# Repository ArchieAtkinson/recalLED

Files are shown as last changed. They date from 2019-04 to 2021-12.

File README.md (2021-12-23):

# recalLED

recalLED is a hand held PCB Simon Says Game. The PCB has four different coloured LEDs and four buttons. Each round a sequence of lights will flash. Once the sequence is over you must use the buttons to input sequence back. If you get it right the green LED flashes and you go to the next level which increase the number of flashes in a sequences. If you lose the red LED will flash and you will go back to the beginning. The game remembers your score and flashes the number of levels you have won when you turn it on. For more information, see the article I wrote about its creation on [my website](https://www.archieatkinson.com/recalled).

This repo contains the Eagle PCB and Schematic Files, Soildworks files for a case and the firmware. The firmware is written using the Arduino IDE and can be uploaded to the MCU using an Arduino as a programmer. It runs off a single CR2032 battery.

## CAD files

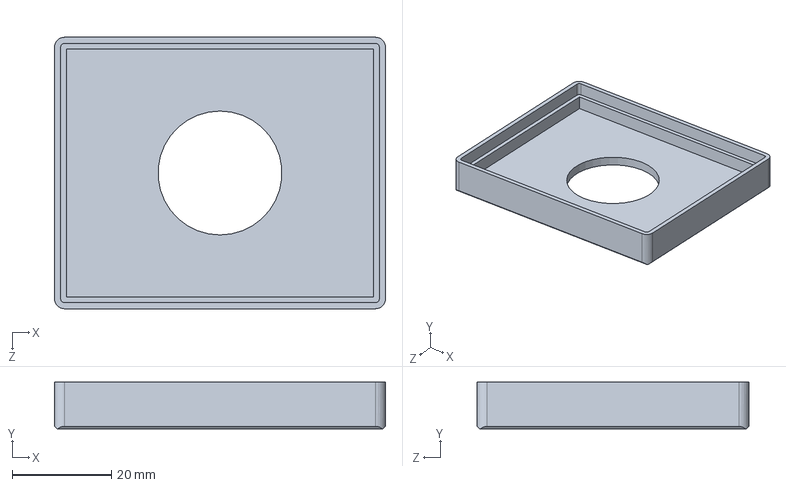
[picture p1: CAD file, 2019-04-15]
SoildWorks Files/Bottom.SLDPRT
66.8 x 9.40 x 54.8 mm

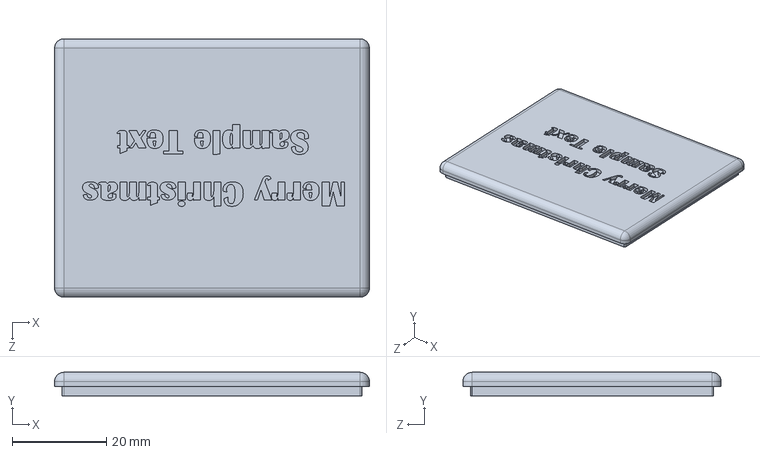
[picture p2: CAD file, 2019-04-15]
SoildWorks Files/Top.SLDPRT
66.8 x 5.00 x 54.8 mm

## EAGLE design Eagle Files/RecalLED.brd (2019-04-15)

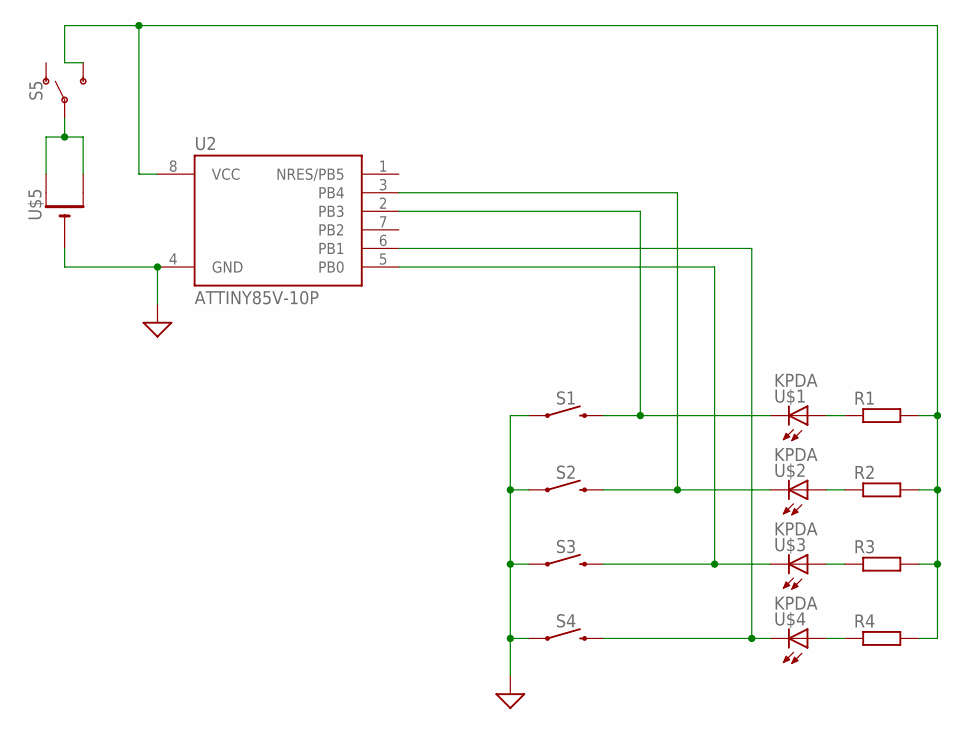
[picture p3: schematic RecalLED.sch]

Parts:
R1, R2, R3, R4: R-EU_M0805; M0805
S1, S2, S3, S4: MOMENTARY-SWITCH-SPST-SMD-6.2MM-TALL; TACTILE_SWITCH_SMD_6.2MM_TALL
S5: SWITCH-SPDT-SMD-RIGHT-ANGLE; SWITCH_SPST_SMD_A
U2: ATTINY85V-10P; PDIP08_300MIL
U$1, U$2, U$3, U$4: KPDA
U$5: CR2032SMT; CR2032-SMD

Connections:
GND: S1.A2 (1), S2.A2 (1), S3.A2 (1), S4.A2 (1), U2.4 (GND), U$5.-
unnamed: S1.B2 (2), U2.2 (PB3), U$1.P$2 (C)
unnamed: S2.B2 (2), U2.3 (PB4), U$2.P$2 (C)
unnamed: S3.B2 (2), U2.5 (PB0), U$3.P$2 (C)
unnamed: S4.B2 (2), U2.6 (PB1), U$4.P$2 (C)
unnamed: R4.1, U$4.P$1 (A)
unnamed: R3.1, U$3.P$1 (A)
unnamed: R2.1, U$2.P$1 (A)
unnamed: R1.1, U$1.P$1 (A)
unnamed: S5.2, U$5.+$1 (+), U$5.+$2 (+1)
unnamed: R1.2, R2.2, R3.2, R4.2, S5.3 (S), U2.8 (VCC)

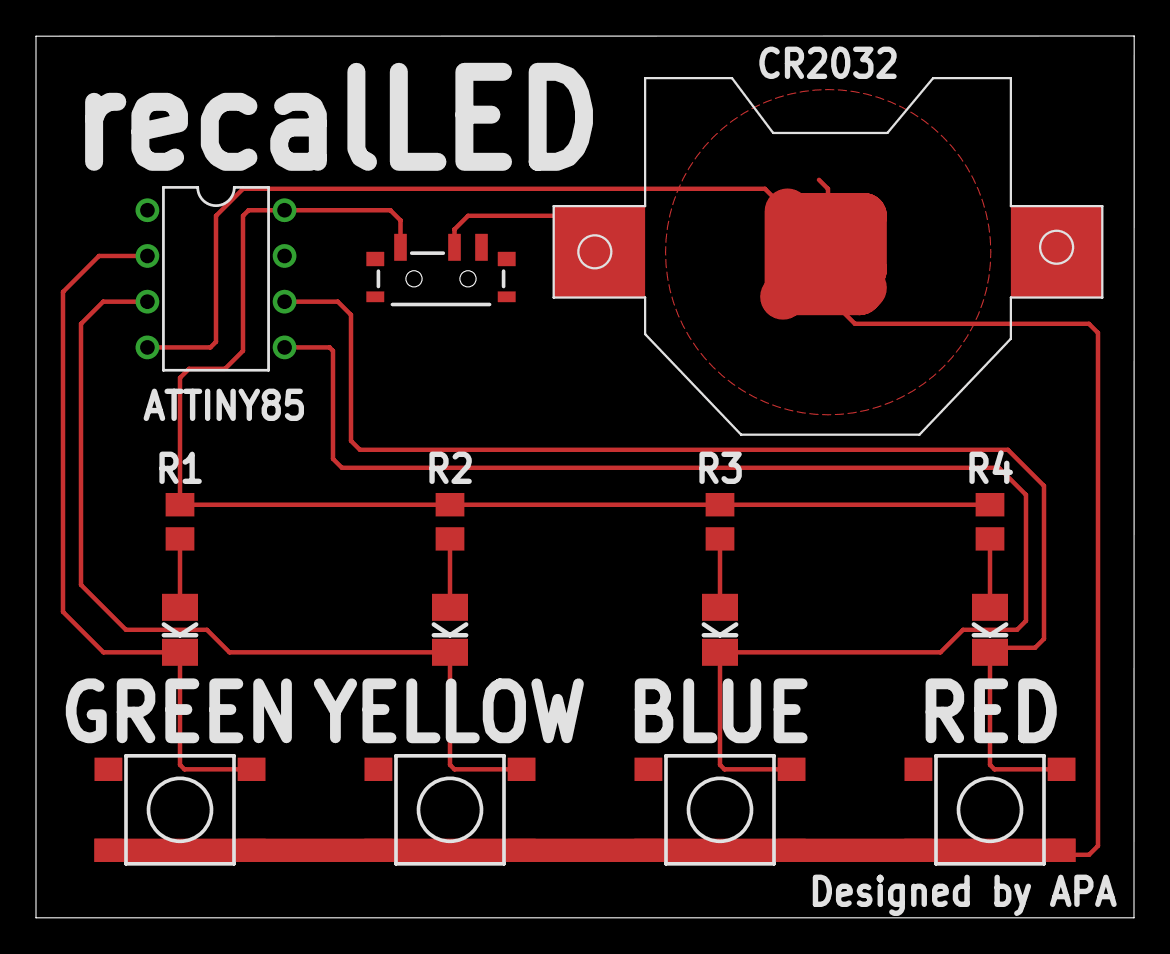
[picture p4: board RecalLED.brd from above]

Board: 2 copper layers, 61.0 x 49.0 mm, 15 parts (0 on the bottom side), 11 nets.

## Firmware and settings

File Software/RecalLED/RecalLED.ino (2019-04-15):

//By ProjectAPA
//Clock = 1MHz
//Has been flashed setting EEPROM byte 0 to 0
//Fuse High bits 3 has change to 1 to enable EEPROM

#include <EEPROM.h> //Allow EEPROM Libary
#define adc_disable() (ADCSRA &= ~(1<<ADEN)) //Disables ADC to save power

//Sets usable pins and number of pins
const int pins[] = {3, 4, 0, 1};
const int pinsLens = 3;

//Unused pin used to generate random number
const int RandPin = 2;

int ran;
int ans[128];
int in[128];

bool wait;

int buttonState[pinsLens + 1];
int lastButtonState[pinsLens + 1];
int reading[pinsLens + 1];
unsigned long lastDebounceTime[pinsLens + 1];

int i;
int j;
bool fail;

unsigned long debounceDelay = 15;
int level = 3;
byte highscore;

void setup()
{
  randomSeed(analogRead(RandPin)); //Gain random seed using unused pin

  //Turns all LED pins to Input with Pull-up
  MCUCR &= ~(1 << PUD);
  DDRB &= ~((1 << DDB0) | (1 << DDB1) | (1 << DDB3) | (1 << DDB4));
  PORTB |= ((1 << PORTB0) | (1 << PORTB1) | (1 << PORTB3) | (1 << PORTB4));
  
  delay(1000);
  
  adc_disable();

  //Starts up some cool flashing lights
  startup();

  delay(750);
  
  //reads high score to be displayed on start up
  highscore = EEPROM.read(0);
  for (i = 0; i < highscore; i++) {
    DDRB |= ((1 << DDB0) | (1 << DDB4));
    PORTB &= ~((1 << PORTB0) | (1 << PORTB4));
    delay(300);
    MCUCR &= ~(1 << PUD);
    DDRB &= ~((1 << DDB0) | (1 << DDB4));
    PORTB |= ((1 << PORTB0) | (1 << PORTB4));
    delay(300);
  }

}

void loop()
{
  delay(500);

  startround();

  delay(750);

  //Randomly flashes LED and store value
  for (i = 0; i <= level; i++) {
    ran = random(0, (pinsLens + 1));
    ans[i] = ran;
    digitalWrite(pins[ran], LOW);
    pinMode(pins[ran], OUTPUT);
    delay(250);
    pinMode(pins[ran], INPUT_PULLUP);
    delay(250);
  }
  
  MCUCR &= ~(1 << PUD);
  DDRB &= ~((1 << DDB0) | (1 << DDB1) | (1 << DDB3) | (1 << DDB4));
  PORTB |= ((1 << PORTB0) | (1 << PORTB1) | (1 << PORTB3) | (1 << PORTB4));


  //Sets debounce vars 
  for (int i = 0; i <= pinsLens; i++) {
    buttonState[i] = HIGH;
    lastButtonState[i] = HIGH;
    lastDebounceTime[i] = 0;
  }
  
  //Goes though each blink of LED and debounces inputs
  for (j = 0; j <= level; j++) {
    wait = true;
    while (wait == true) {
      for (i = 0; i <= pinsLens; i++) {
        reading[i] = digitalRead(pins[i]);

        if (reading[i] != lastButtonState[i]) {
          lastDebounceTime[i] = millis();
        }

        if ((millis() - lastDebounceTime[i]) > debounceDelay) {

          if (reading[i] != buttonState[i]) {
            buttonState[i] = reading[i];

            if (buttonState[i] == LOW) {
              in[j] = i;
              wait = false;
            }
          }
        }
        lastButtonState[i] = reading[i];
      }
    }
  }

  //Comparing all inputs
  fail = false;
  for (i = 0; 127 < ; i++) {
    if (in[i] != ans[i]) {
      fail = true;
      break;
    }
  }

  delay(600);
  //If they got it right advances the level
  if (fail == false) {
    for (i = 0; i < 2; i++) {
      DDRB |= (1 << DDB3);
      PORTB &= ~(1 << PORTB3);
      delay(200);
      MCUCR &= ~(1 << PUD);
      DDRB &= ~(1 << DDB3);
      PORTB |= (1 << PORTB3);
      delay(200);
    }
    level++;
    }
  //If wrong reset, if highscore beaten inform player
  else if (fail == true) {
    for (i = 0; i < 2; i++) {
      DDRB |= (1 << DDB1);
      PORTB &= ~(1 << PORTB1);
      delay(200);
      MCUCR &= ~(1 << PUD);
      DDRB &= ~(1 << DDB1);
      PORTB |= (1 << PORTB1);
      delay(200);
    }

    delay(500);
    
    highscore = EEPROM.read(0);
    if (highscore < (level - 3)) {
      highscore = (level - 3);
      EEPROM.update(0, highscore);
      DDRB |= ((1 << DDB1) | (1 << DDB3));
      PORTB &= ~((1 << PORTB1) | (1 << PORTB3));
      delay(200);
      MCUCR &= ~(1 << PUD);
      DDRB &= ~((1 << DDB1) | (1 << DDB3));
      PORTB |= ((1 << PORTB1) | (1 << PORTB3));
      delay(200);
      DDRB |= ((1 << DDB1) | (1 << DDB3));
      PORTB &= ~((1 << PORTB1) | (1 << PORTB3));
      delay(200);
      MCUCR &= ~(1 << PUD);
      DDRB &= ~((1 << DDB1) | (1 << DDB3));
      PORTB |= ((1 << PORTB1) | (1 << PORTB3));
      
      delay(500);
    }
   
    for (i = 0; i < (level - 3); i++) {
      DDRB |= ((1 << DDB0) | (1 << DDB4));
      PORTB &= ~((1 << PORTB0) | (1 << PORTB4));
      delay(300);
      MCUCR &= ~(1 << PUD);
      DDRB &= ~((1 << DDB0) | (1 << DDB4));
      PORTB |= ((1 << PORTB0) | (1 << PORTB4));
      delay(300);
    }
    delay(500);
    level = 3;
  }

  MCUCR &= ~(1 << PUD);
  DDRB &= ~((1 << DDB0) | (1 << DDB1) | (1 << DDB3) | (1 << DDB4));
  PORTB |= ((1 << PORTB0) | (1 << PORTB1) | (1 << PORTB3) | (1 << PORTB4));
}


void startup()
{

  for (i = 0; i <= pinsLens; i++) {
    digitalWrite(pins[i], LOW);
    pinMode(pins[i], OUTPUT);
    delay(150);
    pinMode(pins[i], INPUT_PULLUP);
    delay(150);
  }
  for (i = (pinsLens-1); i >= 0; i--) {
    digitalWrite(pins[i], LOW);
    pinMode(pins[i], OUTPUT);
    delay(150);
    pinMode(pins[i], INPUT_PULLUP);
    delay(150);
  }

}

void startround()
{
  DDRB |= ((1 << DDB0) | (1 << DDB1) | (1 << DDB3) | (1 << DDB4));
  PORTB &= ~((1 << PORTB0) | (1 << PORTB1) | (1 << PORTB3) | (1 << PORTB4));

  delay(750);

  MCUCR &= ~(1 << PUD);
  DDRB &= ~((1 << DDB0) | (1 << DDB1) | (1 << DDB3) | (1 << DDB4));
  PORTB |= ((1 << PORTB0) | (1 << PORTB1) | (1 << PORTB3) | (1 << PORTB4));

  for (i = 0; i < 127; i++) {
    ans[i] = 0;
    in[i] = 0;
  }
  fail = false;
}

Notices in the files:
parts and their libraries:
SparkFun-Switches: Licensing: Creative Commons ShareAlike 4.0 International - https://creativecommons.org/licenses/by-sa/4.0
